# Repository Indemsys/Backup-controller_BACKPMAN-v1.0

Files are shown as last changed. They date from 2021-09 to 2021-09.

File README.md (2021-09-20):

 # Плата контроллера резервного питания BACKPMAN v1.0
 (Backup power management controller)

 - Описание схемы (https://habr.com/ru/post/557242/) 
 - Описание разработки платы (https://habr.com/ru/post/562462/)
 - Установка Azure RTOS (https://habr.com/ru/post/573352/)
 - Технологии отладки и тюнинг платы (https://habr.com/ru/post/574088/)  

Animated

PCB_removed_bg_

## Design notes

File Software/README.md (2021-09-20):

Демонстрационные программные проекты на базе платы контроллера 

- AzureRTOS_hello_word - проект портирования Azure RTOS и вывода Hello Word  в UART
- AzureRTOS_profiling - пример организации задач и использования сервисов Azure RTOS
- Regulated_power_source - демонстрационный проект управляемого источника напряжения

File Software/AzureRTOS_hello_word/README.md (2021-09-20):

Описание данного программного проекта в этой статье - (https://habr.com/ru/post/573352/)

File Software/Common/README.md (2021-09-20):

Общая директория в которой храняться файлы используемые разными проектами

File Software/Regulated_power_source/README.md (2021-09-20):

- Описание данного программного проекта в этой статье - (https://habr.com/ru/post/574088/)

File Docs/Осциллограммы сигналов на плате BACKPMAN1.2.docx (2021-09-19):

# Осциллограммы сигналов на плате BACKPMAN v1.2

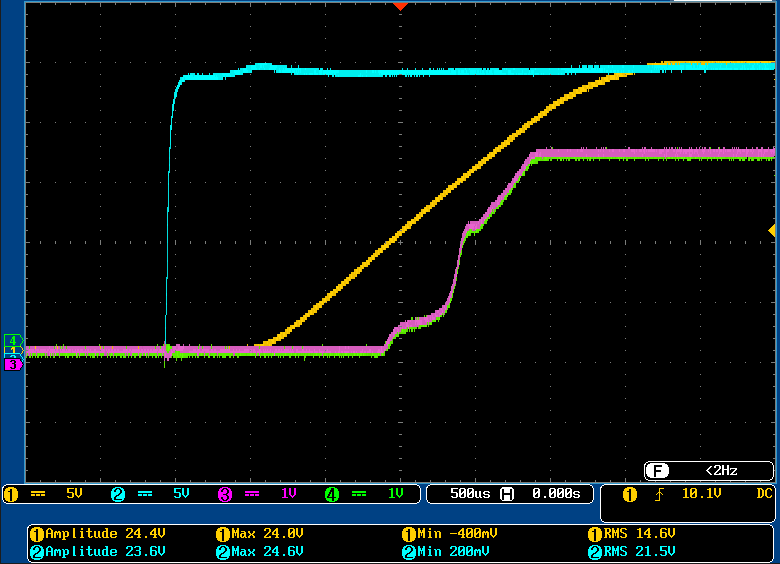
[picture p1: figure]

| Осциллограмма нарастания напряжения на клемах источника питания (PSRC), системной шине питания (SYS_PWR), напряжения питания +3V3 и сигнале PIDS_FAULT в момент подачи скачкообразного напряжения на разъем внешнего источника питания при отсутствии аккумулятора Нагрузка на системной шине в это время – резистор 33 Ом, ток 0.72 А при 24 В Время нарастанания системного напряжения – около 2.5 мс

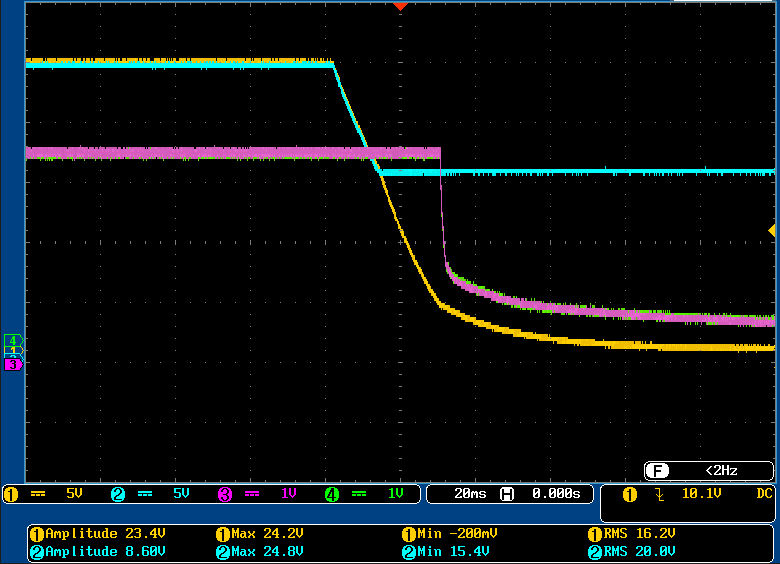
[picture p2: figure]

| Осциллограмма спада напряжения на клемах источника питания (PSRC), системной шине питания (SYS_PWR), напряжения питания +3V3 и сигнале PIDS_FAULT в момент резкого отключения внешнего источника питания и при отсутствии аккумулятора Нагрузка на системной шине в это время – резистор 33 Ом, ток 0.72 А при 24 В Как видно сигнал предупреждения PIDS_FAULT не успевает выставиться до того как упадет напряжение в системе.

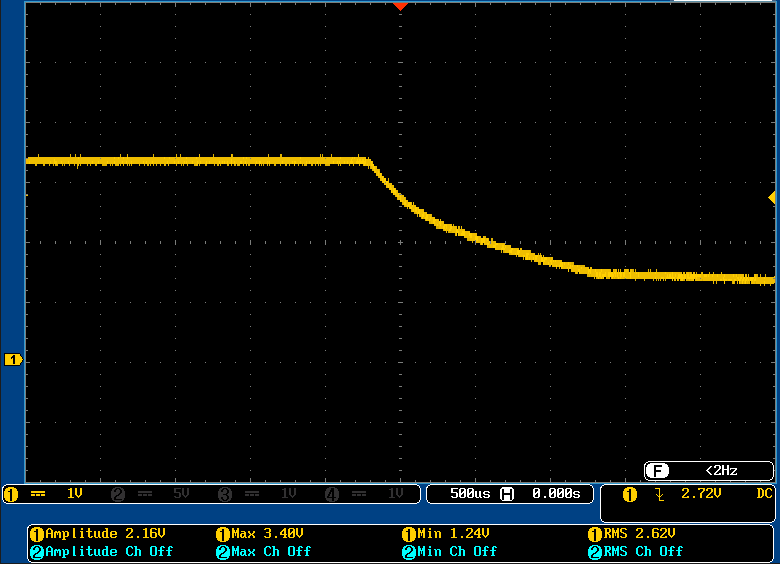
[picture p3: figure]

| Осциллограмма спада напряжения питания +3V3 в момент резкого отключения внешнего источника питания при отсутствии аккумулятора Нагрузка на системной шине в это время – резистор 33 Ом, ток 0.72 А при 24 В Как видно микроконтроллеру остается меньше 100 мкс чтобы выполнить действия по сохранению эергонезависимых переменных

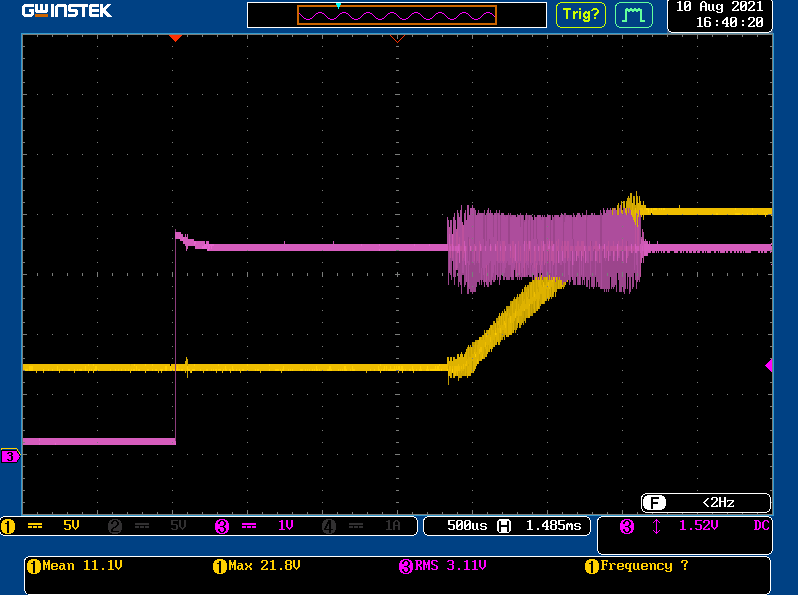
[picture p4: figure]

| Осциллограмма включения DCDC преобразователя Cигнал EN_CHARGER включает работу DCDC преобразователя. Желтый - сигнал на выходе DCDC преобразователя. Нагрузка на выходе DCDC преобразователя - 5 Ом.

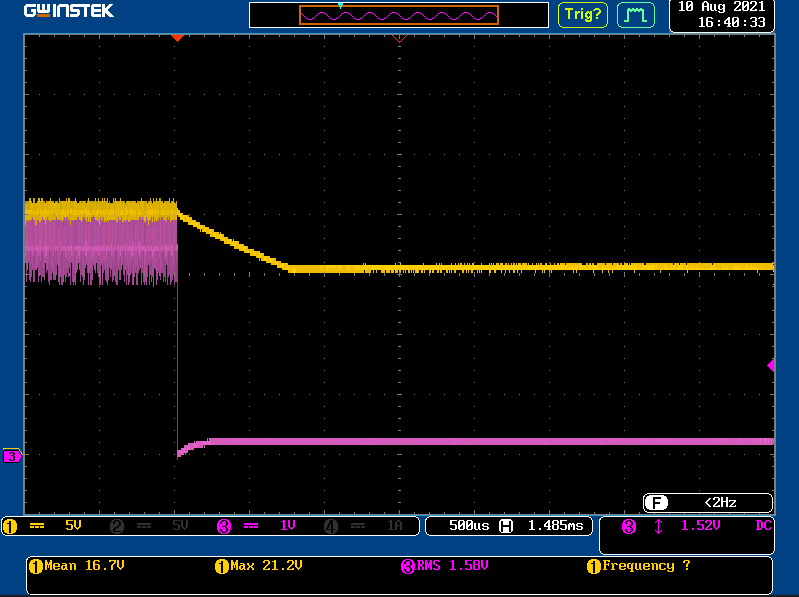
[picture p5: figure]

| Осциллограмма отключения DCDC преобразователя Сигнал EN_CHARGER выключает работу DCDC преобразователя. Желтый- сигнал на выходе DCDC преобразователя. Нагрузка на выходе DCDC преобразователя - 5 Ом. При достижении 15В нагрузка автоматически отключается ключом.

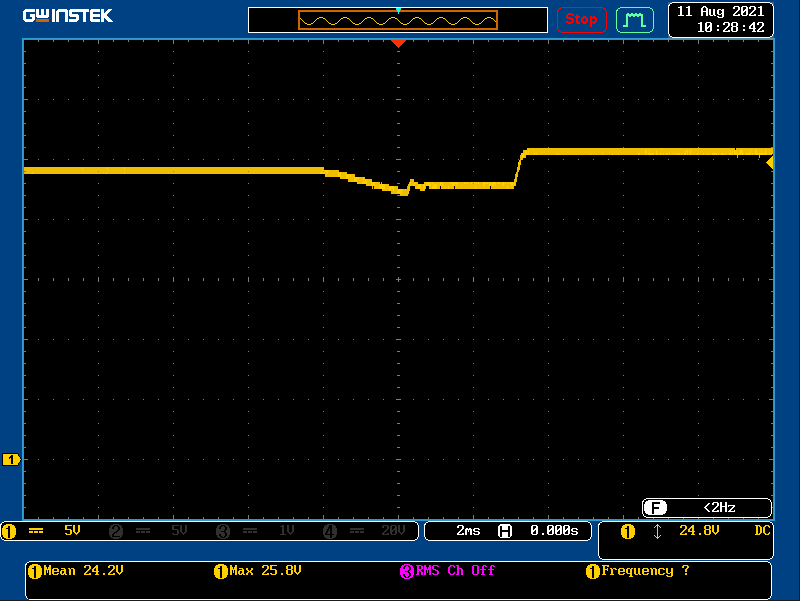
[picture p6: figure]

| Осциллограмма момента переключения системной шины питания с внешнего источника питания на питание от аккумулятора в момент когда внешнее питание отключается и сигнал AIDS_SHDN находится в лог. 1 Нагрузка на системной шине в это время – резистор 33 Ом

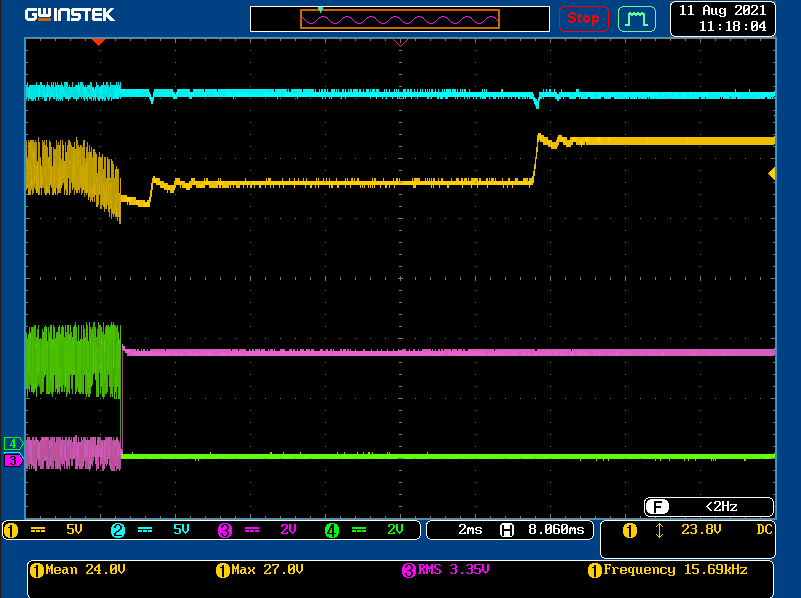
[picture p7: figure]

| Осциллограмма момента переключения системной шины питания с внешнего источника питания на питание от аккумулятора в момент когда внешнее питание отключается и сигнал AIDS_SHDN находится в лог. 0 Голубой – напряжение на аккумуляторе Желтый – напряжение на системной шине питания SYS_PWR Розовый – сигнал AIDS_SHDN. Включает работу идеального диода от аккумулятора в системную шину питания Зеленый – сигнал EN_CHARGER Нагрузка на системной шине в это время – резистор 33 Ом . Сигнал AIDS_FBC в лог. 0

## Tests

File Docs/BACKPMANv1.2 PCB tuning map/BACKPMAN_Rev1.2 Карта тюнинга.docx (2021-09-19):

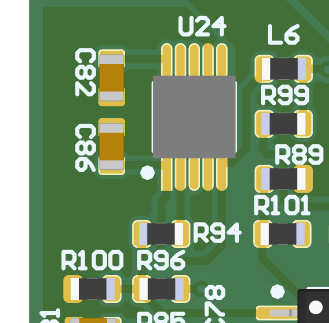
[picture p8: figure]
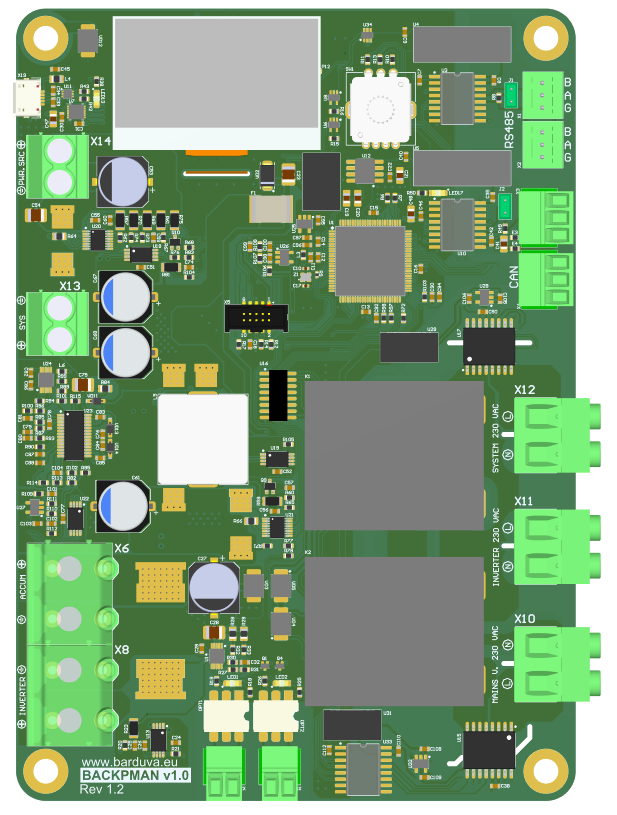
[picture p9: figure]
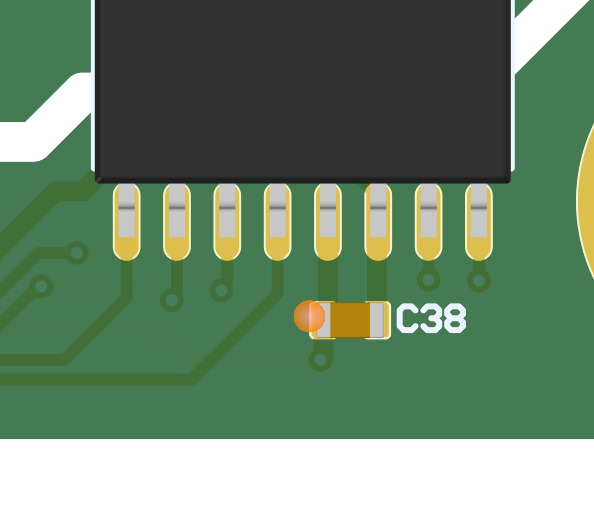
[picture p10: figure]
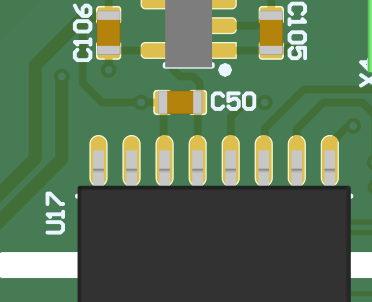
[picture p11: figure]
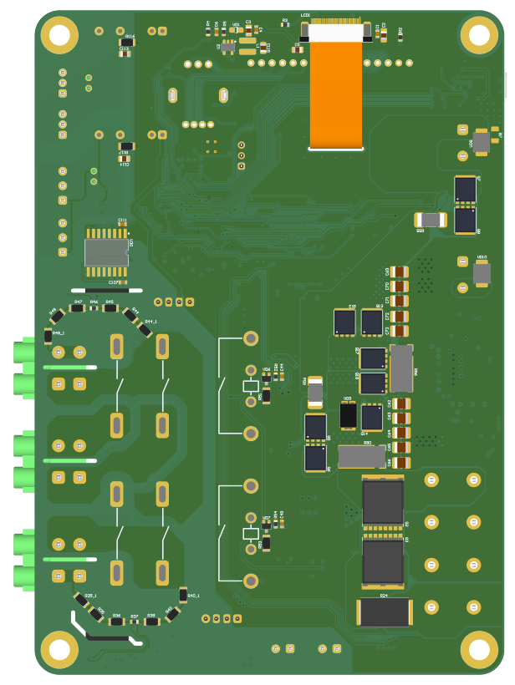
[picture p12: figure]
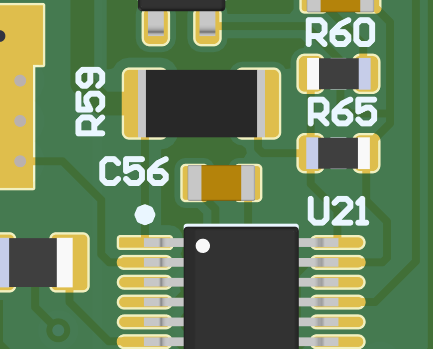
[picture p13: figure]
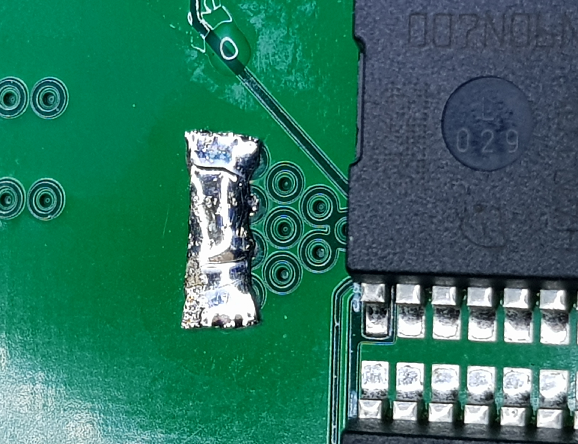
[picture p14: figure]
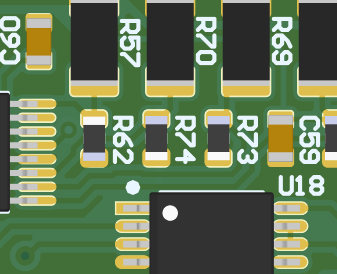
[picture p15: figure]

R100 заменить на 15k

R94 заменить на 9.1k

Соединить 14-й и 15-й выводы

Соединить 14-й и 15-й выводы

R46 заменить на 910 Ом

R37 заменить на 910 Ом

С56 удалить

Замкнуть площадки переходных отверстий на окружающий их полигон

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
Напять стабилитроны EDZVFHT2R16B между затвором и истоком транзисторов Q5, Q6, Q7, Q8. Катоды стабилитронов на затворы транзисторов

8.

R74 заменить на 220k

4.

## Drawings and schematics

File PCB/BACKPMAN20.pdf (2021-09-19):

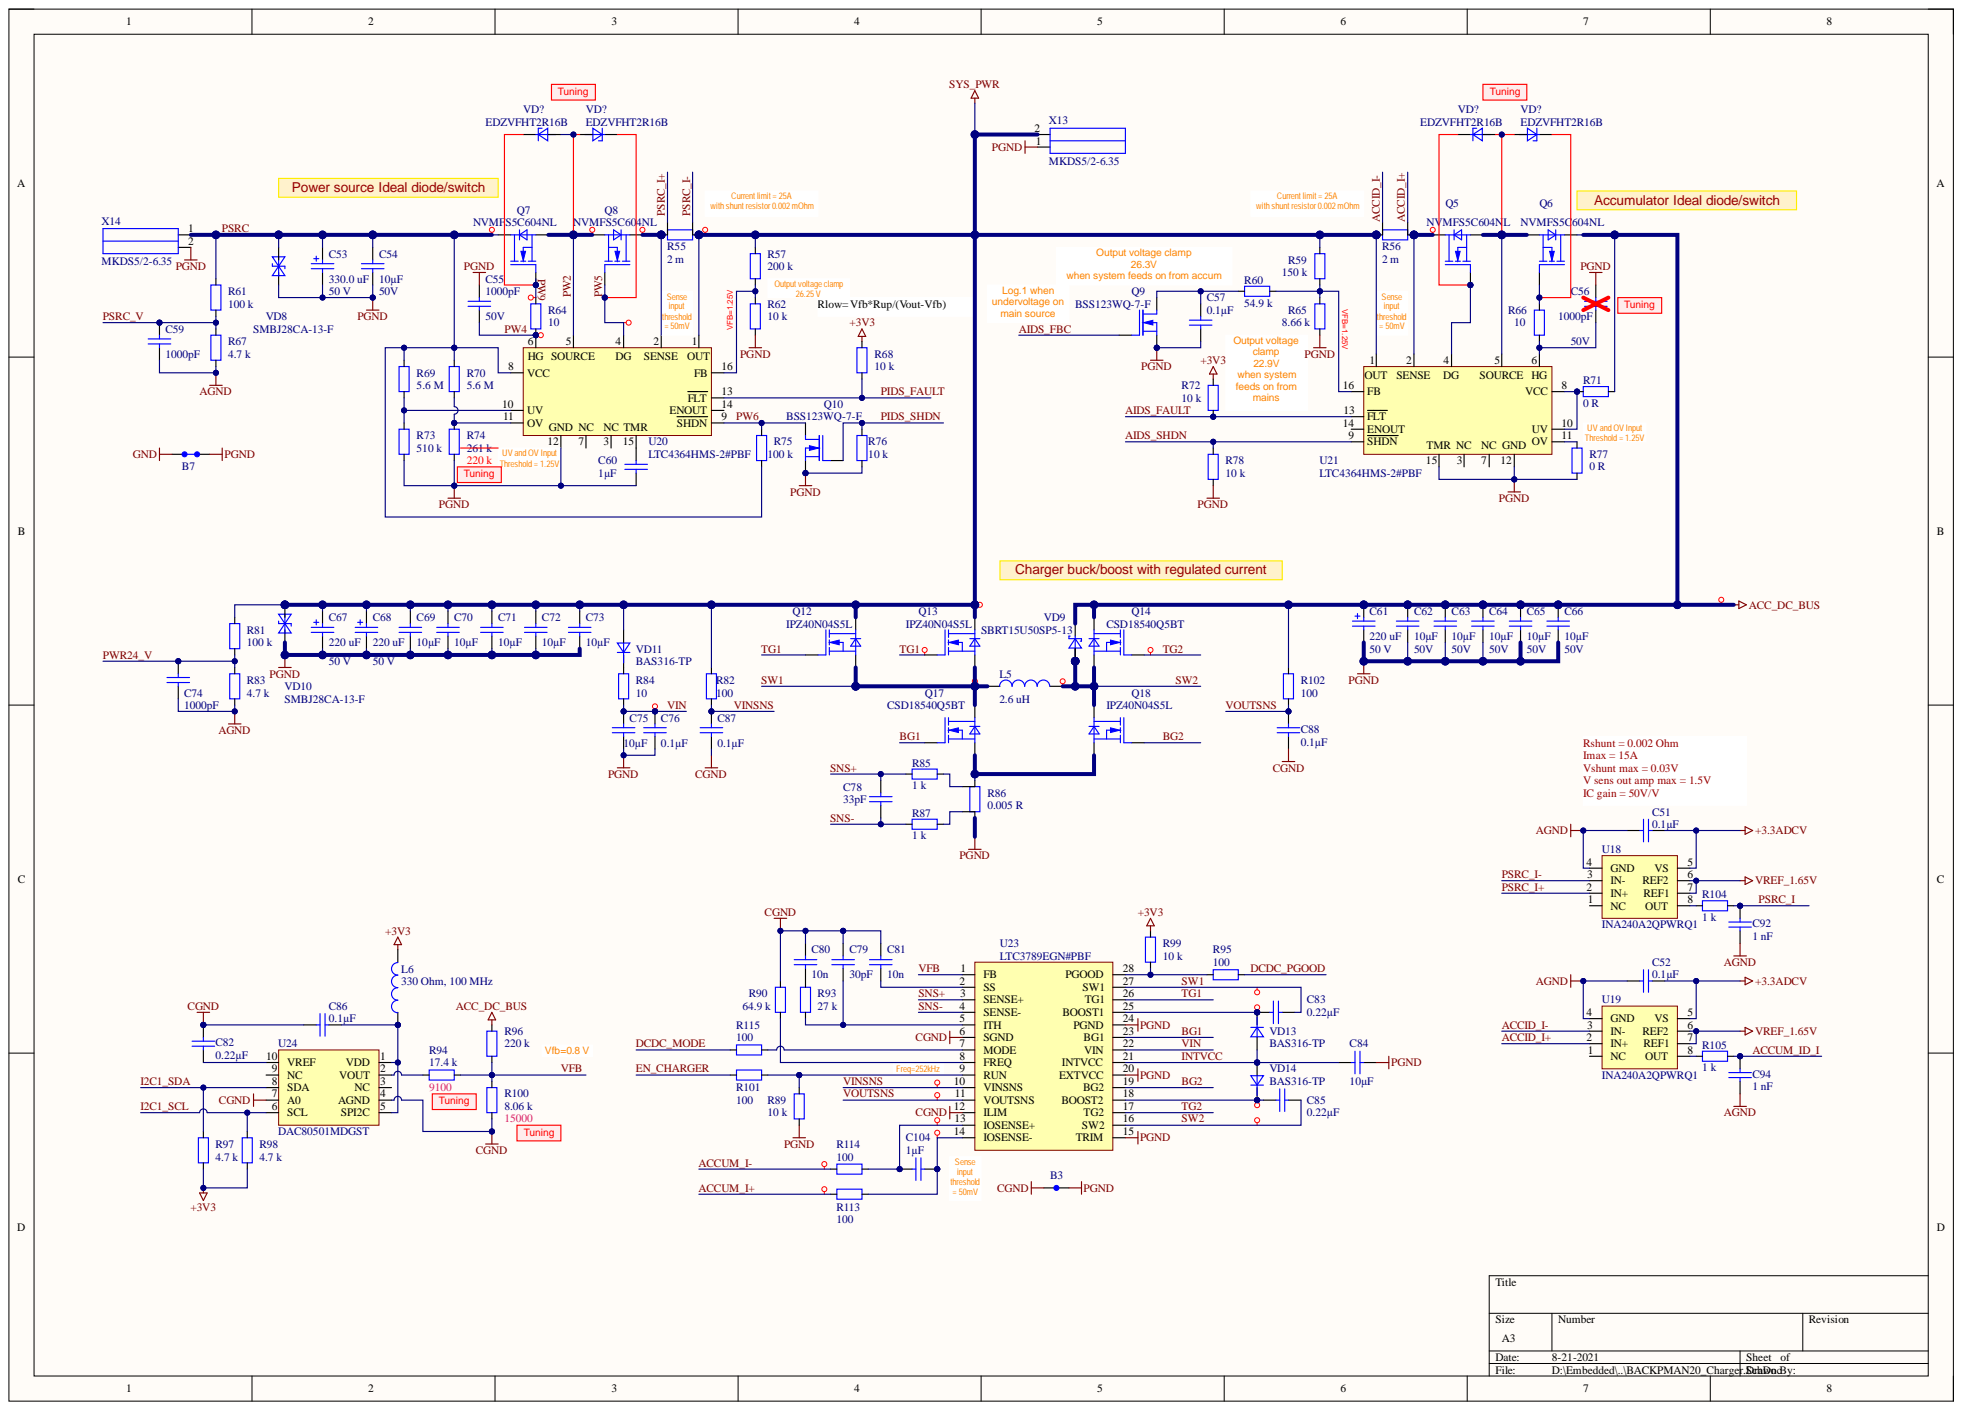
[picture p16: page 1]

Power source Ideal diode/switch

Accumulator Ideal diode/switch

when system feeds on from accum

Rlow=Vfb*Rup/(Vout-Vfb)

220 k | UV and OV Input Threshold = 1.25V

Tuning

Charger buck/boost with regulated current

Rshunt = 0.002 Ohm
Imax = 15A
Vshunt max = 0.03V
V sens out amp max = 1.5V
IC gain = 50V/V

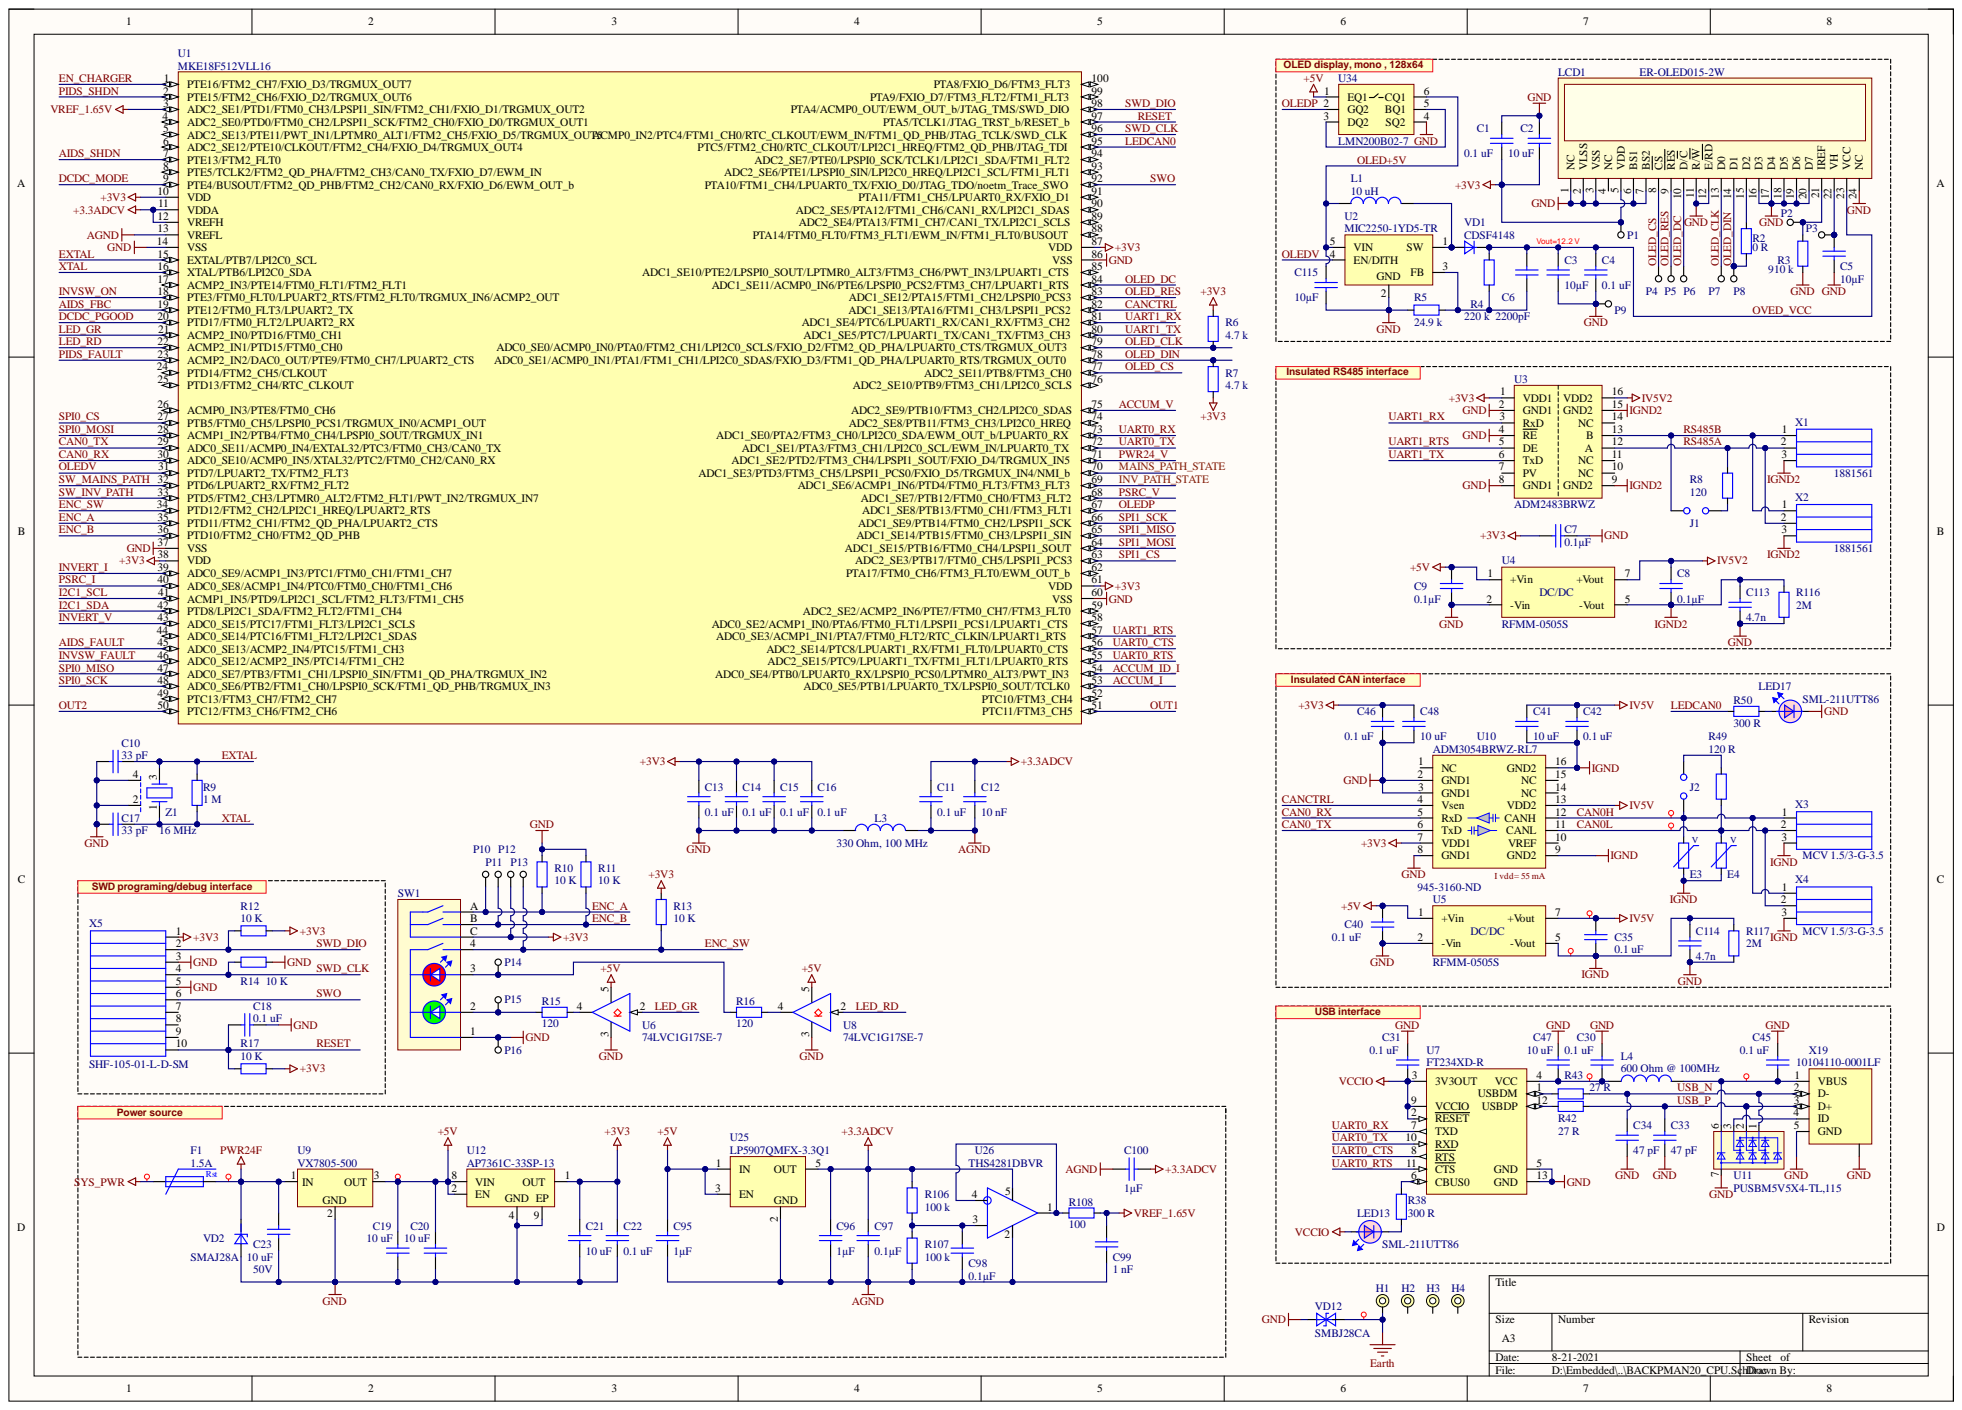
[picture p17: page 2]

PTB5/FTM0_CH5/LPSPI0_PCS1/TRGMUX_IN0/ACMP1_OUT 27 ACMP1_IN2/PTB4/FTM0_CH4/LPSPI0_SOUT/TRGMUX_IN1 28 ADC0_SE11/ACMP0_IN4/EXTAL32/PTC3/FTM0_CH3/CAN0_TX 29 ADC0_SE10/ACMP0_IN5/XTAL32/PTC2/FTM0_CH2/CAN0_RX 30 PTD7/LPUART2_TX/FTM2_FLT3 31 PTD6/LPUART2_RX/FTM2_FLT2 32 PTD5/FTM2_CH3/LPTMR0_ALT2/FTM2_FLT1/PWT_IN2/TRGMUX_IN7 33 PTD12/FTM2_CH2/LPI2C1_HREQ/LPUART2_RTS 34 PTD11/FTM2_CH1/FTM2_QD_PHA/LPUART2_CTS 35 PTD10/FTM2_CH0/FTM2_QD_PHB 36 VSS 37 | RxD 3

SWD programing/debug interface

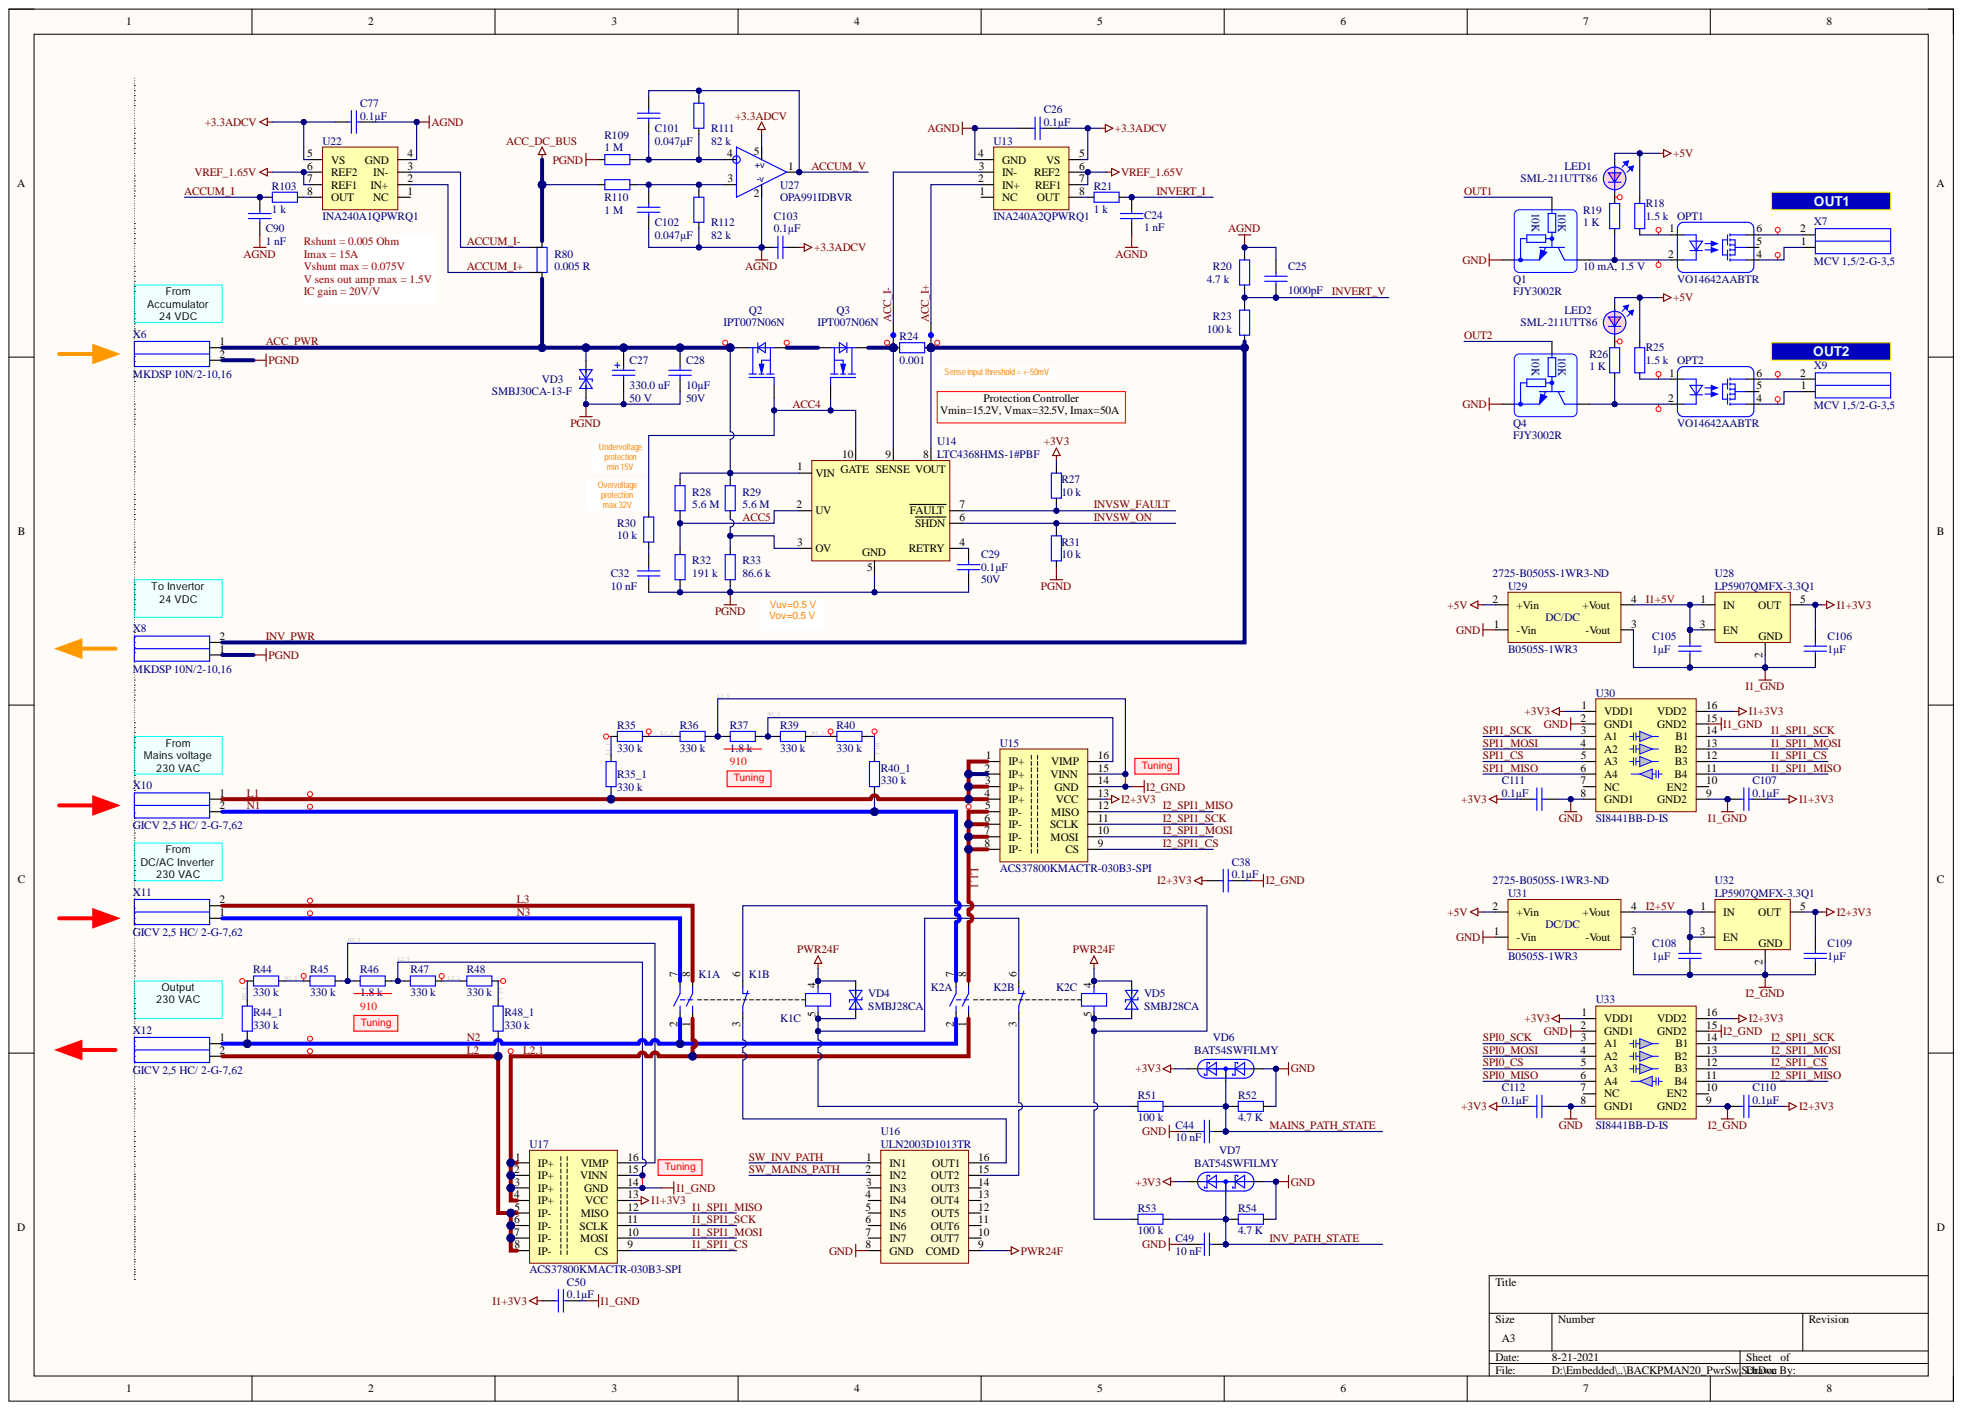
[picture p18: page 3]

Rshunt = 0.005 Ohm
Imax = 15A
Vshunt max = 0.075V
V sens out amp max = 1.5V
IC gain = 20V/V

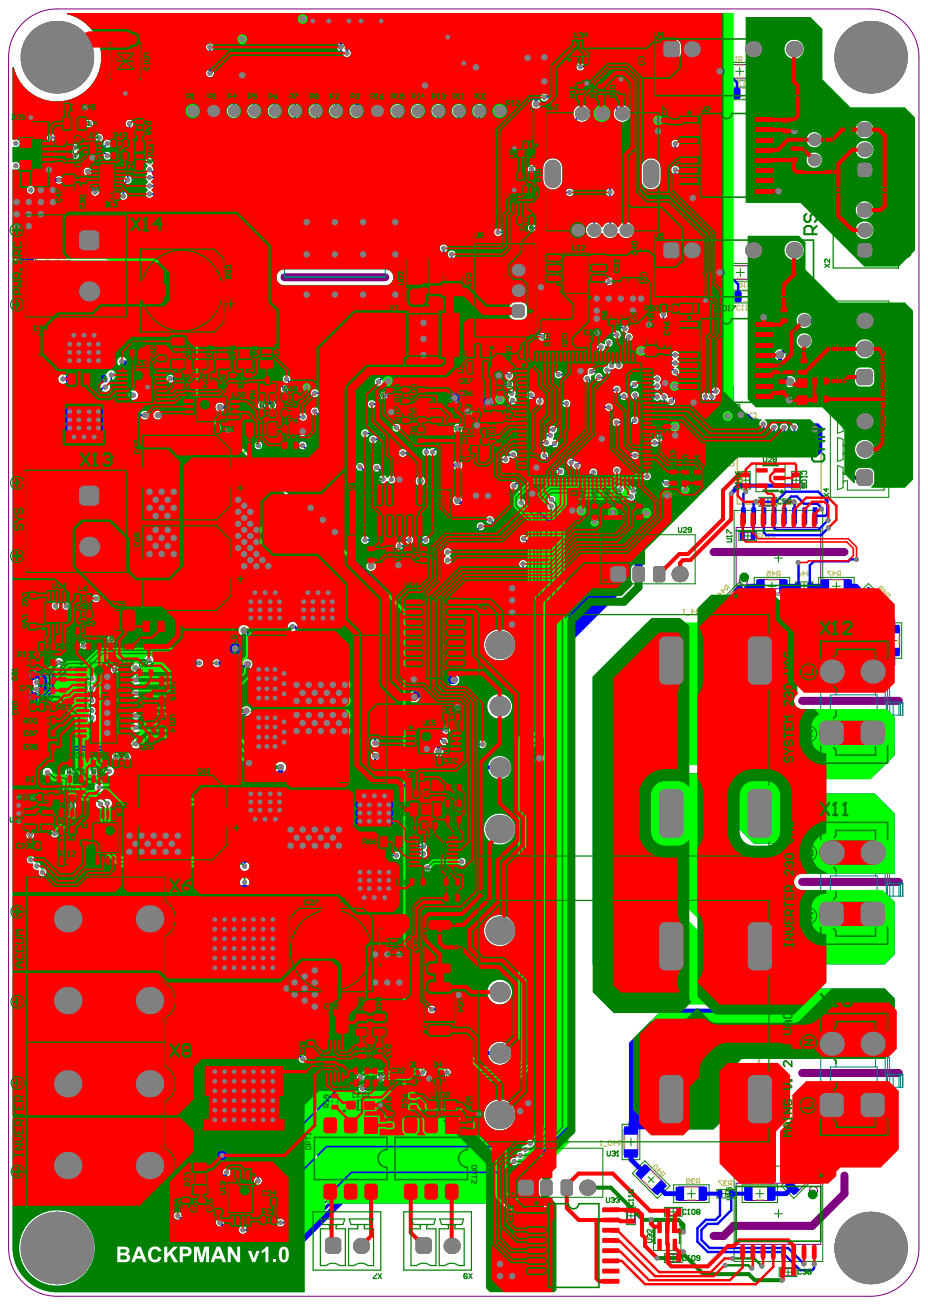
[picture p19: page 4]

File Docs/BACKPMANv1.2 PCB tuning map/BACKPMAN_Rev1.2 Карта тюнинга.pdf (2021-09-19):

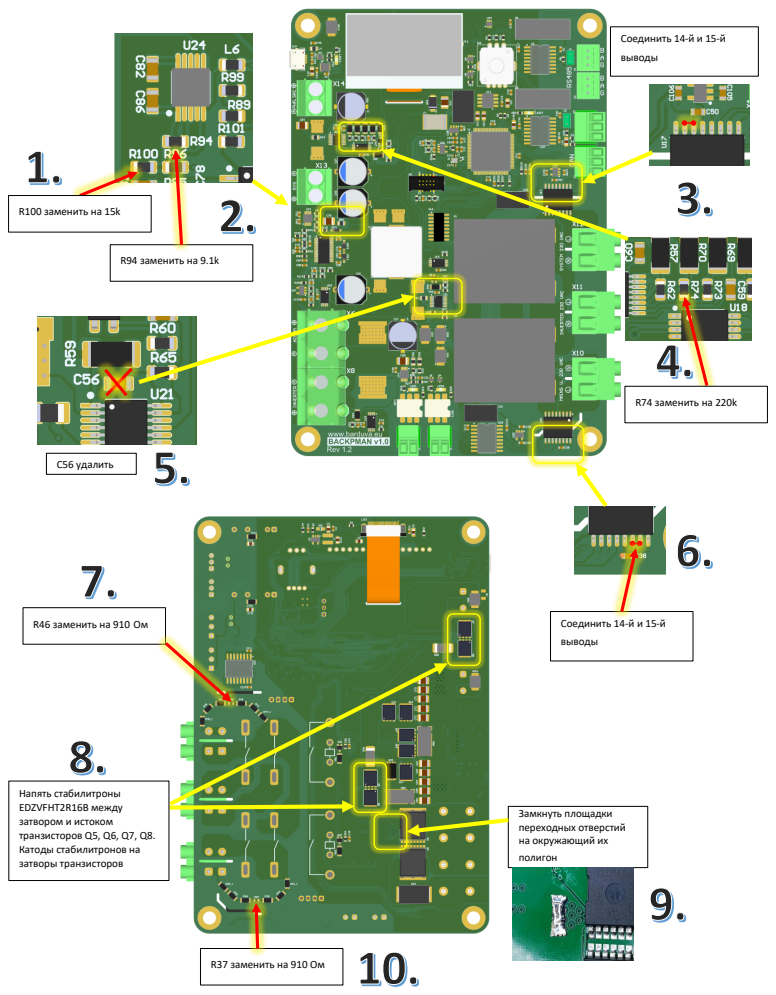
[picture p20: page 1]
R100 заменить на 15k; R94 заменить на 9.1k; Соединить 14-й и 15-й; выводы; С56 удалить; R74 заменить на 220k

R46 заменить на 910 Ом

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

Замкнуть площадки
переходных отверстий
на окружающий их
полигон

R37 заменить на 910 Ом

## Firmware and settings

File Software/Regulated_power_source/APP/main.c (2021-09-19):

#define  _MAIN_GLOBALS_
#include "App.h"



#define DEMO_LPUART          LPUART0
#define DEMO_LPUART_CLKSRC   kCLOCK_ScgSysPllAsyncDiv2Clk
#define DEMO_LPUART_CLK_FREQ CLOCK_GetIpFreq(kCLOCK_Lpuart0)

uint8_t                       recv_buffer[1];

uint8_t                       background_buffer[32];


#define uart_task_PRIORITY   (configMAX_PRIORITIES - 1)

TX_THREAD                     main_thread;
#pragma data_alignment=8
uint8_t                       thread_main_stack[THREAD_MAIN_STACK_SIZE];
static void                   Thread_main(ULONG initial_input);
static TX_EVENT_FLAGS_GROUP   app_flags_grp;

/*-----------------------------------------------------------------------------------------------------
  Вызывается сразу после старта по цепочке:  Reset_Handler -> SystemInit -> SystemInitHook

  \param void
-----------------------------------------------------------------------------------------------------*/
void SystemInitHook(void)
{
  BCKUPC10_init_pins();
}

/*-----------------------------------------------------------------------------------------------------


  \param void

  \return int
-----------------------------------------------------------------------------------------------------*/
int main(void)
{
  BOARD_BootClockRUN();
  Init_DMA();
  Init_outputs_states();
  tx_kernel_enter();
}


/*-----------------------------------------------------------------------------------------------------
  Вызывается из tx_kernel_enter

  \param first_unused_memory
-----------------------------------------------------------------------------------------------------*/
void    tx_application_define(void *first_unused_memory)
{
  tx_thread_create(&main_thread, "Main", Thread_main,
    0,
    (void *)thread_main_stack, // stack_start
    THREAD_MAIN_STACK_SIZE,   // stack_size
    THREAD_MAIN_PRIORITY,     // priority. Numerical priority of thread. Legal values range from 0 through (TX_MAX_PRIORITES-1), where a value of 0 represents the highest priority.
    THREAD_MAIN_PRIORITY,     // preempt_threshold. Highest priority level (0 through (TX_MAX_PRIORITIES-1)) of disabled preemption. Only priorities higher than this level are allowed to preempt this thread. This value must be less than or equal to the specified priority. A value equal to the thread priority disables preemption-threshold.
    TX_NO_TIME_SLICE,
    TX_AUTO_START);
}

/*-----------------------------------------------------------------------------------------------------
  Функция передачи флагов в главный поток

  \param flags
-----------------------------------------------------------------------------------------------------*/
void App_set_events(uint32_t flags)
{
  tx_event_flags_set(&app_flags_grp, flags, TX_OR);
}

/*-----------------------------------------------------------------------------------------------------


  \param void
-----------------------------------------------------------------------------------------------------*/
static void Periodic_PIT_callback(void)
{
  App_set_events(FLAG_PERIODIC_TICK);
}

/*-----------------------------------------------------------------------------------------------------


  \param void
-----------------------------------------------------------------------------------------------------*/
static void Time_PIT_callback(void)
{
  system_sec_counter++;
}


/*-----------------------------------------------------------------------------------------------------


  \param initial_input
-----------------------------------------------------------------------------------------------------*/
static void Thread_main(ULONG initial_input)
{
  uint32_t err = 0;

  SIM->CHIPCTL &= ~((3 << 6) | (3 << 4));
  SIM->CHIPCTL |=(1 << 6) | (2 << 4); // На CLKOUT (pin 24) выводим частоту PLL деленную на 4
  SCG->CLKOUTCNFG =(6 << 24);

  // Выполняем контрольный замер времени одновременно эта задержка служит для обеспечения установления референсных напряжений в чипе
  ref_time = Measure_reference_time_interval(REF_TIME_INTERVAL);

  App_create_pool_memry();
  tx_event_flags_create(&app_flags_grp, "Main");

  Thread_idle_create();
  AppLogg_init();

  PIT_init_module();
  // Запускаем генератор прерываний для отсчета времени
  PIT_init_channel(TIME_PIT_TIMER, TIME_TICK_PERIOD, TIME_PIT_PRIO, 1,  Time_PIT_callback);
  ADCs_subsystem_init();                 // Инициализируем работу многоканального АЦП
  Outputs_init();

  // Запускаем генератор прерываний для генерации события FLAG_PERIODIC_TICK
  PIT_init_channel(SCAN_TASK_PIT_TIMER, OUTPUT_TICK_PERIOD, PIT1_PRIO, 1,  Periodic_PIT_callback);

  BCKUPC10_I2C1_Init();
  Set_DCDC_DAC_code(DCDC_DAC_Volt_to_code(0.0f));

  SPI_Init(U15_SPI_ID);
  SPI_Init(U17_SPI_ID);

  Set_output_off(OUTP_LED_GREEN);
  Set_output_off(OUTP_LED_RED);

  LOGs(__FUNCTION__, __LINE__, SEVERITY_DEFAULT,"################### Main task started ###################");

  FLASH_set_EEPROM_condition();          // Проверяем и устанавливаем если надо нужную конфигурацию размера EEPROM
  Restore_NV_parameters();               // Переписывает в RAM параметры и установки из EEPROM

  Thread_CAN_create();

  //wvar.vcom_mode = 0;
  if (wvar.vcom_mode == 0)
  {
    if (Get_ENC_SW()==0 )
    {
      FreeMaster_task_create();
    }
    else
    {
      Task_VT100_create(&uart0_driver, 0);
    }
  }
  else
  {
    if (Get_ENC_SW()==0 )
    {
      Task_VT100_create(&uart0_driver, 0);
    }
    else
    {
      FreeMaster_task_create();
    }
  }

  if (ACS37800_test() != RES_OK) err++;
  if (DCDC_DAC_initializing() != RES_OK) err++;

  if (err> 0)
  {
    LOGs(__FUNCTION__, __LINE__, SEVERITY_DEFAULT,"System stopped. Failure state");
    while (1)
    {
      time_delay(10);
    }
  }

  Mem_man_log_statistic();

  while (1)
  {
    ULONG  actual_flags;
    if (tx_event_flags_get(&app_flags_grp, FLAG_ADC_DONE | FLAG_PERIODIC_TICK, TX_OR_CLEAR ,&actual_flags, MS_TO_TICKS(100)) == TX_SUCCESS)
    {

      // Обработка флага завершения заполнения новых отсчетов ADC.
      // Флаг FLAG_ADC_DONE устанавливается в процедуре прерывания по окончании цикла DMA
      // Передачи DMA вызываются по окончании выборок ADC
      // Выборки ADC вызываются по сигналу таймера PIT0
      if (actual_flags & FLAG_ADC_DONE)          // Период 1024 мкс
      {
        //ITM_EVENT8(1,1);

        BCKUPC10_Inputs_handling();              //
        Manual_Encoder_handling();
        Signals_conditioning();
        OLED_control_function();                 // 0.69 мкс
        Outputs_state_automat();                 // 4.9 мкс
        Synchronize_output_signals();            // 1.3 мкс
        App_set_events(FLAG_POWER_CONTROL_TICK); // 3.15 мкс
        ACS37800_read();                         // 58 мкс
        DCDC_DAC_refresh();                      // 117 мкс
                                                 //
        //ITM_EVENT8(1,0);
      }


      // Флаг FLAG_PERIODIC_TICK выставляется в процедуре прерывания от таймера PIT2
      if (actual_flags & FLAG_PERIODIC_TICK)     // Период 1000 мкс
      {
      }
    }
    else
    {
      time_delay(10);
    }
  }
}

/*-----------------------------------------------------------------------------------------------------
  Расчет значений с плавающей точкой.
  Время выполнения без оптимизации 3.69 мкс, с оптимизацией - 2.8 мкс


  \param void
-----------------------------------------------------------------------------------------------------*/
void Signals_conditioning(void)
{
  TX_INTERRUPT_SAVE_AREA
  static uint32_t cn    = 0;
  static float    sum_i = 0;
  static uint32_t cpu_overheat_cnt = 0;
  static uint8_t  prev_overheat_state = 0;


  //ITM_EVENT8(1,1);
  TX_DISABLE;
  sys.accum_id_i       =  Value_fp_ACCUM_ID_I(sys.fp_smpl_accum_id_i);
  sys.accum_i          =  Value_fp_ACCUM_I(sys.fp_smpl_accum_i);
  sys.psrc_i           =  Value_fp_PSRC_I(sys.fp_smpl_psrc_i);
  sys.invert_i         =  Value_fp_INVERT_I(sys.fp_smpl_invert_i);
  sys.invert_v         =  Value_fp_INVERT_V(sys.fp_smpl_invert_v);
  sys.sys_v            =  Value_fp_SYS_V(sys.fp_smpl_sys_v);
  sys.psrc_v           =  Value_fp_PSRC_V(sys.fp_smpl_psrc_v);
  sys.accum_v          =  Value_fp_ACCUM_V(sys.fp_smpl_accum_v);
  sys.accum_sum_i      =  sys.invert_i - sys.accum_i;
  sys.cpu_temper       =  CPU_TEMP(sys.fp_smpl_cpu_temper);

  if (Value_INV_PATH_STATE(Get_INV_PATH_STATE()) < 3.0f)
  {
    sys.mains_path_state = 1;
  }
  else
  {
    sys.mains_path_state = 0;
  }

  if (Value_MAINS_PATH_STATE(Get_MAINS_PATH_STATE()) < 3.0f)
  {
    sys.inv_path_state   = 1;
  }
  else
  {
    sys.inv_path_state   = 0;
  }

  sys.pwr_src_power = sys.psrc_i * sys.psrc_v;
  if (sys.accum_sum_i > 0)
  {
    sys.accum_charge_power = -sys.accum_i * sys.accum_v;
    sys.accum_discharge_power = 0;
    sys.chaging_pwr_loss = sys.pwr_src_power - sys.accum_charge_power;
    sys.charging_efficiency =(sys.accum_charge_power / sys.pwr_src_power) * 100;
  }
  else
  {
    sys.accum_charge_power = 0;
    sys.accum_discharge_power = sys.accum_sum_i * sys.accum_v;
    sys.chaging_pwr_loss = 0;
    sys.charging_efficiency = 0;
  }

  // Расчет количества заряда в аккумуляторе
  if (cn < 1000)
  {
    cn++;
    sum_i += sys.accum_sum_i;
  }
  else
  {
    cn = 0;
    sys.accum_charge += sum_i * ((float)MAIN_CYCLE_PERIOD_US)/(1000000.0f*60.0f*60.0f);
    sum_i = 0;
  }
  TX_RESTORE;

  // Обнаружитель перегрева
  if (sys.cpu_temper > MAX_CPU_TEMPERATURE)
  {
    if (prev_overheat_state == 1)
    {
      uint32_t bound = MAIN_CYCLE_PERIOD_US;
      bound =  1000000ul/bound ;
      cpu_overheat_cnt++;
      if (cpu_overheat_cnt > bound) // Фиксируем перегрев если температура продержалась выше границы более 1 сек
      {
        sys.cpu_overheat = 1;
        cpu_overheat_cnt--;
      }
    }
    else
    {
      cpu_overheat_cnt = 0;
      prev_overheat_state = 1;
    }
  }
  else
  {
    if (prev_overheat_state == 0)
    {
      uint32_t bound = MAIN_CYCLE_PERIOD_US;
      bound =  10000000ul/bound ;
      cpu_overheat_cnt++;
      if (cpu_overheat_cnt > bound) // Сбрасываем перегрев если температура продержалась ниже границы более 10 сек
      {
        sys.cpu_overheat = 0;
        cpu_overheat_cnt--;
      }
    }
    else
    {
      cpu_overheat_cnt=0;
      prev_overheat_state = 0;
    }
  }


  if (Get_float_val(&sys.vrms_u15) > MIN_MAINS_VOLTAGE)
  {
    sys.mains_voltage_ok = 1;
  }
  else
  {
    sys.mains_voltage_ok = 0;
  }

  if (Get_float_val(&sys.vrms_u17) > MIN_OUTPUT_VOLTAGE)
  {
    sys.output_voltage_ok = 1;
  }
  else
  {
    sys.output_voltage_ok = 0;
  }

  sys.out220v_power = Get_float_val(&sys.vrms_u17)*Get_float_val(&sys.irms_u17);



  //ITM_EVENT8(1,0);
}

/*-----------------------------------------------------------------------------------------------------
  Запаковать состояние системы в 8-и байтный пакет CAN
  Функция вызывается из задачи CAN

  \param buf
-----------------------------------------------------------------------------------------------------*/
void Pack_sytem_state_to_can_msg(uint8_t* out_buf)
{
  T_sys_state_packet pkt;

  memset(out_buf, 0, 8);
  memset(&pkt, 0, sizeof(pkt));

  pkt.charging_active  = 0;
  pkt.accum_charge = 0;

  pkt.mains_voltage_ok  = sys.mains_voltage_ok;
  pkt.output_voltage_ok = sys.output_voltage_ok;
  pkt.iverter_is_on     = Get_INVSW_ON();
  pkt.iverter_relay     = sys.inv_path_state;
  pkt.mains_relay       = sys.mains_path_state;
  pkt.iverter_power     = (uint32_t)sys.out220v_power;

  memcpy(out_buf, &pkt, sizeof(pkt));
}

/*-----------------------------------------------------------------------------------------------------
  Выполнить команду поступившую в 8-и байтном пакете CAN
  Функция вызывается из задачи CAN

  \param cmd_buf
-----------------------------------------------------------------------------------------------------*/
void Execute_can_command(uint8_t* cmd_buf)
{


}

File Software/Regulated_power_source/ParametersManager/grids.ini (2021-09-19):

[Main]
Version=2

[frmMain.grid_Params_View: TcxGridDBTableView]
=
SourceDPI=96
Footer="True"
GroupByBox="True"
GroupFooters=0
NewItemRow="False"
EditFormUseDefaultLayout="True"
ColumnsQuickCustomizationSorted="False"
Version=1

[frmMain.grid_Params_View/grid_Params_ID: TcxGridDBColumn]
=
SourceDPI=96
FilterRowOperator=0
GroupIndex=-1
IsChildInMergedGroup="False"
Width=20
AlignmentHorz=1
Index=0
Visible="False"
SortOrder="soNone"
SortIndex=-1
WasVisibleBeforeGrouping="False"

[frmMain.grid_Params_View/grid_Params_SubNumber: TcxGridDBColumn]
=
SourceDPI=96
FilterRowOperator=0
GroupIndex=-1
IsChildInMergedGroup="False"
Width=25
AlignmentHorz=1
Index=1
Visible="True"
SortOrder="soAscending"
SortIndex=0
WasVisibleBeforeGrouping="False"

[frmMain.grid_Params_View/grid_Params_sublevel: TcxGridDBColumn]
=
SourceDPI=96
FilterRowOperator=0
GroupIndex=0
IsChildInMergedGroup="False"
Width=140
AlignmentHorz=0
Index=2
Visible="False"
SortOrder="soAscending"
SortIndex=1
WasVisibleBeforeGrouping="True"

[frmMain.grid_Params_View/grid_Params_ParameterDescription: TcxGridDBColumn]
=
SourceDPI=96
FilterRowOperator=0
GroupIndex=-1
IsChildInMergedGroup="False"
Width=385
AlignmentHorz=0
Index=3
Visible="True"
SortOrder="soNone"
SortIndex=-1
WasVisibleBeforeGrouping="False"

[frmMain.grid_Params_View/grid_Params_ParameterName: TcxGridDBColumn]
=
SourceDPI=96
FilterRowOperator=0
GroupIndex=-1
IsChildInMergedGroup="False"
Width=121
AlignmentHorz=0
Index=4
Visible="True"
SortOrder="soNone"
SortIndex=-1
WasVisibleBeforeGrouping="False"

[frmMain.grid_Params_View/grid_Params_Parameter_variable_name: TcxGridDBColumn]
=
SourceDPI=96
FilterRowOperator=0
GroupIndex=-1
IsChildInMergedGroup="False"
Width=146
AlignmentHorz=0
Index=5
Visible="True"
SortOrder="soNone"
SortIndex=-1
WasVisibleBeforeGrouping="False"

[frmMain.grid_Params_View/grid_Params_ParameterType: TcxGridDBColumn]
=
SourceDPI=96
FilterRowOperator=0
GroupIndex=-1
IsChildInMergedGroup="False"
Width=35
AlignmentHorz=0
Index=6
Visible="True"
SortOrder="soNone"
SortIndex=-1
WasVisibleBeforeGrouping="False"

[frmMain.grid_Params_View/grid_Params_defval: TcxGridDBColumn]
=
SourceDPI=96
FilterRowOperator=0
GroupIndex=-1
IsChildInMergedGroup="False"
Width=37
AlignmentHorz=1
Index=7
Visible="True"
SortOrder="soNone"
SortIndex=-1
WasVisibleBeforeGrouping="False"

[frmMain.grid_Params_View/grid_Params_minval: TcxGridDBColumn]
=
SourceDPI=96
FilterRowOperator=0
GroupIndex=-1
IsChildInMergedGroup="False"
Width=33
AlignmentHorz=1
Index=8
Visible="True"
SortOrder="soNone"
SortIndex=-1
WasVisibleBeforeGrouping="False"

[frmMain.grid_Params_View/grid_Params_maxval: TcxGridDBColumn]
=
SourceDPI=96
FilterRowOperator=0
GroupIndex=-1
IsChildInMergedGroup="False"
Width=33
AlignmentHorz=1
Index=9
Visible="True"
SortOrder="soNone"
SortIndex=-1
WasVisibleBeforeGrouping="False"

[frmMain.grid_Params_View/grid_Params_ParameterAlias: TcxGridDBColumn]
=
SourceDPI=96
FilterRowOperator=0
GroupIndex=-1
IsChildInMergedGroup="False"
Width=67
AlignmentHorz=0
Index=10
Visible="True"
SortOrder="soNone"
SortIndex=-1
WasVisibleBeforeGrouping="False"

[frmMain.grid_Params_View/grid_Params_attr: TcxGridDBColumn]
=
SourceDPI=96
FilterRowOperator=0
GroupIndex=-1
IsChildInMergedGroup="False"
Width=32
AlignmentHorz=0
Index=11
Visible="True"
SortOrder="soNone"
SortIndex=-1
WasVisibleBeforeGrouping="False"

[frmMain.grid_Params_View/grid_Params_pdefval: TcxGridDBColumn]
=
SourceDPI=96
FilterRowOperator=0
GroupIndex=-1
IsChildInMergedGroup="False"
Width=93
AlignmentHorz=0
Index=12
Visible="True"
SortOrder="soNone"
SortIndex=-1
WasVisibleBeforeGrouping="False"

[frmMain.grid_Params_View/grid_Params_format: TcxGridDBColumn]
=
SourceDPI=96
FilterRowOperator=0
GroupIndex=-1
IsChildInMergedGroup="False"
Width=43
AlignmentHorz=0
Index=13
Visible="True"
SortOrder="soNone"
SortIndex=-1
WasVisibleBeforeGrouping="False"

[frmMain.grid_Params_View/grid_Params_varlen: TcxGridDBColumn]
=
SourceDPI=96
FilterRowOperator=0
GroupIndex=-1
IsChildInMergedGroup="False"
Width=45
AlignmentHorz=1
Index=14
Visible="True"
SortOrder="soNone"
SortIndex=-1
WasVisibleBeforeGrouping="False"

[frmMain.grid_Params_View/col_Params_SelectorID: TcxGridDBColumn]
=
SourceDPI=96
FilterRowOperator=0
GroupIndex=-1
IsChildInMergedGroup="False"
Width=81
AlignmentHorz=0
Index=15
Visible="True"
SortOrder="soNone"
SortIndex=-1
WasVisibleBeforeGrouping="False"

[frmMain.grid_Params_View/grid_Params_func: TcxGridDBColumn]
=
SourceDPI=96
FilterRowOperator=0
GroupIndex=-1
IsChildInMergedGroup="False"
Width=20
AlignmentHorz=0
Index=16
Visible="True"
SortOrder="soNone"
SortIndex=-1
WasVisibleBeforeGrouping="False"

[frmMain.grid_Params_View/ConditionalFormattingProvider: TcxGridConditionalFormattingProvider]
=
Count=0

[grid_ParamsTree.grid_ParamsTree: TcxDBTreeList]
=
SourceDPI=96
ColumnsQuickCustomizationSorted="False"
BandsQuickCustomizationSorted="False"

[grid_ParamsTree.grid_ParamsTree/Bands: TcxTreeListBands]
=
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

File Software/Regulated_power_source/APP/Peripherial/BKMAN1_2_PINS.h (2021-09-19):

#ifndef BACKPMAN10_PINS_H
  #define BACKPMAN10_PINS_H

typedef struct
{
    GPIO_Type      *gpio;
    PORT_Type      *port;
    unsigned char  pin_num;
    unsigned char  irqc; //  Interrupt Configuration
                         //  0000 Interrupt/DMA Request disabled.
    //  0001 DMA Request on rising edge.
    //  0010 DMA Request on falling edge.
    //  0011 DMA Request on either edge.
    //  0100 Reserved.
    //  1000 Interrupt when logic zero.
    //  1001 Interrupt on rising edge.
    //  1010 Interrupt on falling edge.
    //  1011 Interrupt on either edge.
    //  1100 Interrupt when logic one.
    unsigned char  lock; //  if 1 Pin Control Register bits [15:0] are locked and cannot be updated until the next System Reset.
    unsigned char  mux;  //  Pin Mux Control
                         //  000 Pin Disabled (Analog).
    //  001 Alternative 1 (GPIO).
    //  010 Alternative 2 (chip specific).
    //  011 Alternative 3 (chip specific).
    //  100 Alternative 4 (chip specific).
    //  101 Alternative 5 (chip specific).
    //  110 Alternative 6 (chip specific).
    //  111 Alternative 7 (chip specific / JTAG / NMI).
    unsigned char  DSE; // 0 Low drive strength is configured on the corresponding pin, if pin is configured as a digital output.
                        // 1 High drive strength is configured on the corresponding pin, if pin is configured as a digital output.
    unsigned char  ODE;  // 0 Open Drain output is disabled on the corresponding pin.
                         // 1 Open Drain output is enabled on the corresponding pin, provided pin is configured as a digital output.
    unsigned char  PFE;  // 0 Passive Input Filter is disabled on the corresponding pin.
                         // 1 Passive Input Filter is enabled on the corresponding pin.
    unsigned char  PUPD; // 00 Internal pull-up or pull-down resistor is not enabled on the corresponding pin.
                         // 10 Internal pull-down resistor is enabled on the corresponding pin, if the corresponding Port Pull Enable Register bit is set.
    // 11 Internal pull-up resistor is enabled on the corresponding pin, if the corresponding Port Pull Enable Register bit is set.
    unsigned char  dir;  // 0 Pin is configured as general purpose input, if configured for the GPIO function
                         // 1 Pin is configured for general purpose output, if configured for the GPIO function
    unsigned char  init; // Init state

} T_IO_pins_configuration;

  #define   ANAL          0  // Pin Disabled (Analog).
  #define   ALT0          0  // Pin Disabled (Analog).
  #define   GPIO          1  // Alternative 1 (GPIO).
  #define   ALT1          1  // Alternative 1 (GPIO).
  #define   ALT2          2  //
  #define   ALT3          3  //
  #define   ALT4          4  //
  #define   ALT5          5  //
  #define   ALT6          6  //
  #define   ALT7          7  //

  #define   DSE_LO        0 // 0 Low drive strength is configured on the corresponding pin, if pin is configured as a digital output.
  #define   DSE_HI        1 // 1 High drive strength is configured on the corresponding pin, if pin is configured as a digital output.

  #define   OD_DIS        0 // 0 Open Drain output is disabled on the corresponding pin.
  #define   OD__EN        1 // 1 Open Drain output is enabled on the corresponding pin, provided pin is configured as a digital output.

  #define   PFE_DIS       0 // 0 Passive Input Filter is disabled on the corresponding pin.
  #define   PFE__EN       1 // 1 Passive Input Filter is enabled on the corresponding pin.

  #define   FAST_SLEW     0 // 0 Fast slew rate is configured on the corresponding pin, if pin is configured as a digital output.
  #define   SLOW_SLEW     1 // 1 Slow slew rate is configured on the corresponding pin, if pin is configured as a digital output.


  #define   PUPD_DIS      0 // 00 Internal pull-up or pull-down resistor is not enabled on the corresponding pin.
  #define   PULL__DN      2 // 10 Internal pull-down resistor is enabled on the corresponding pin, if the corresponding Port Pull Enable Register bit is set.
  #define   PULL__UP      3 // 11 Internal pull-up resistor is enabled on the corresponding pin, if the corresponding Port Pull Enable Register bit is set.

  #define   GP_INP        0 // 0 Pin is configured as general purpose input, if configured for the GPIO function
  #define   GP_OUT        1 // 1 Pin is configured for general purpose output, if configured for the GPIO function
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
